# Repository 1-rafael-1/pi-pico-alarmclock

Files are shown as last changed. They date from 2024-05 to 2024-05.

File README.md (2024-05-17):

# pi-pico-alarmclock

Building a working alarmclock based on a Raspberry Pi Pico W

The general idea is to build a device that can reliably wake up my kids who are in an age range, where this is a challenge. So it should sport these features:

+ be somewhat Star wars - themed (not my idea)
+ have a display that shows the time and some other information
+ have a speaker that can play music or sounds, and loudly so
  + have a way to hold music/sound files for that purpose
+ have a thingy that can turn on a bright light, ideally an array of RGB LEDs or some such. Because "when my room is still dark, I cannot properly wake up"
+ have some buttons to set the alarm time and to toggle the alarm
  + without making it too easy to silence the actual alarm when it is going off
+ have the ability to both run on battery power or be powered by a USB charger
+ be built into some enclosure that looks nice, is easy enough to print and assemble and can somehow house the components in a sensible way
+ be fun for daddy to build and program

State of affairs: Wiring and coding is done. There is one issue left to fix (Sound is unreliable, will not turn on as expected 50% of the time).
So this is next: Figure out this bug and then off to designing&printing a case.

## Disclaimer

This project is one of my first projects using MicroPython and electronics. I have some background in software development with niche/proprietary languages and no background at all in electronics and Python. So most of this I figured out as I went.
That being said: This is going to be full of imperfections. Use any of this at Your own risk and in case You spot my mistakes, I am glad to hear of them! Besides that I am happy if this is useful or fun for somebody.

## Description

+ The display shows the current time. A lightsaber-symbol indicates, if the alarm is active or not. A battery indicator shows the battery charge or indicated the device is currently usb-powered.
+ To get the current time, on startup and every 6 hours subsequently the device will connect to Wifi, get the time from a timeserver and update the RTC with that.
+ Button-driven operations:
  + The green button will toggle the alarm active/inactive, when in normal operation mode
  + The yellow button will toggle system info being displayed or the normal time mode being displayed
  + The blue button will enter the mode for setting the alarm time. The current alarm time will be displayed (blinking) and the top area will display a symbol indicating that we are doing some sort of setup.
    + In this mode the green button will increase the hour digits and the yellow button will increase the minutes digits. Pressing blue again will save the new alarm time and resume normal operation.
+ Analog clock: The NeoPixel will show an approximation of an analog clock when in normal operation. The blue light indicates seconds, the green light indicates minutes and the red one indicates hours. When hands meet, their color is mixed. (I know... but I had way too much fun)
+ Alarm:
  + 5 Minutes before the alarm time the NeoPixel will turn off the analog clock and simulate a sunrise, going from few and red lights to more and warm-white lights.
  + At the same time in the indicator area of the display we will show a random color as text, using the button colors. Pressing the appropriate button will proceed to show the next color, until one has pressed all three buttons in the order the device wanted them. Completing the sequence will abort the alarm at any stage. The assumption is: If You are awake enough to have found and pressed the buttons in the random order that You were presented, You should be awake enough to get out of bed.
  + At the actual alarm time the sunrise will becompleted and the NeoPixel will display some fancy lighshow-things. At the same time the Music starts tom play, in my case here I chose the Imperial March, because that is what the kids love.

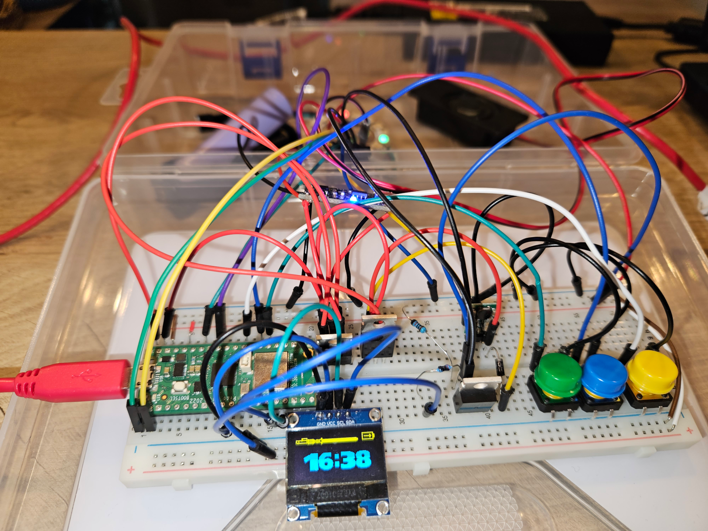
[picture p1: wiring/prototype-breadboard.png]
Prototype on breadboard


## Code

The code project is structured into these main parts: `main.py`, `classes`, and `drivers` as well as `settings` and `media`. 

|part|contents|
|:--|:--|
|main.py|Main script, doing very little besides instantiating.|
|drivers|Drivers and helpers for specific components. I have written none of these myself, each file has a comment saying where I found it.|
|classes|Classes for each logical component used in this project.|
|settings|A few `json` files to remember settings and magic strings.|

One file in settings is not checked into this repository for obvious reasons. Add one `wifi.json` to settings, structured like this:

```json
{
    "ssid": "YOUR SSID",
    "password": "YOUR PASSWORD"
}
```

### Testing and Tests

After a while this projects code got quite messy and I spent a fair amount of time restructuring it into classes with a small brother of dependency injection. This not only helped me to escape dependency hell but also allows for easy mocking and testing in isolation. I did write some tests here and there, typically where I ran into some problem that i was too lazy to iron out by manually testing the full application over and over again. None of this is perfect, but it sure was fun to do.

What I still sorely miss is a way to debug MicroPython Code. Writing anything remotely complex without is no fun.

### media

The folder contains images used for displaying things on the OLED display. The OLED driver provides only very limited support for text, there is no way i found to change font, font size and also (not an issue here) we cannot display all German letters. So if one wants some nicer numbers, some nice state indicators and the like one has to use images. I have used [GIMP](https://www.gimp.org/) to create these images. I have used the `Export as...` function to export them as 'pbm' files. They have to be converted to indexed color and when exporting to pbm they have to be exported as 'raw' format. The OLED driver can then read these files and display them on the screen.

A really good tutorial on how to create these images can be found [here](https://blog.martinfitzpatrick.com/displaying-images-oled-displays/). I would not have figured this out without.

## Components and Wiring

The central part of this project is the Raspberry Pi Pico W. I am sure everything could be done with a different microcontroller, as long as MicroPython is supported. I chose the Pico W because... I had one.

### Components

|Component|Description|
|---|---|
|Microcontroller|Raspberry Pi Pico W|
|OLED Display|SSD1306 compatible I²C OLED Display 128*64 pixels with two color yellow/blue. Input Voltage 3.3V - 5V, but must support 3.3V because that is what we are using. Single-color will work just as well, since the colors are actually fixed to sections of the display and cannot be coded.|
|battery|I use a 18650 Lithium-Polymer battery with 3350mAh. Anything else will work, als long as it fits with the charger module, battery holder and puts out no more than 5V, since You will be plugging it into Pi Pico and the step-up-converter.|
|battery holder|really anything will do, that can hold one Lithium-Polymer unit. Consider adding a switch between battery and charger or be as lazy as me and take out the battery whenever You want to truly power down.|
|charger module|I used a TC4056A module, capable of drawing power from Micro-USB or input pads and capable to charge/discharge the above battery safely.|
|NeoPixel ring|I used WS2812B with 16 RGB LED on it. If You want more LED make sure to check if You can power them safely. Each LED will draw ~60mA and that quickly exceeds either the 300mA the Pico can supply directly or what the step-up-converter attached to the USB or battery power supplies can deliver. In my case here the step-up-converter is rated for 1000mA and so this should be okay.|
|step-up converter|A step up capable to convert 2.5V - 5V to steady 5V. I used BS01 (sometimes found as MT-3608 or HW-085). Required to power the NeoPixel-Ring. There are a ton of these things available everywhere, make sure it is DC-DC and can put out 1000mA for 5V and can convert to that from whatever You expect to come out of Your power supply.|
|speaker|I have used DFplayer Mini 3 Watt 8 Ohm speaker, 70*30*15mm. They can be found in some flavors from multiple vendors. Depending on the form factor You may need to adjust the case, but I guess that cannot be helped since there are so many different of these speakers around.|
|p-channel MOSFET|Two used to switch power modules. I have used IRF9540 which is overkill and and more efficient options exist. These things are rated for up to 100V and the switching voltage is uncomfortably close to USB typical ~5V. So, maybe they now have a higher voltage drop from source to drain, than I would like.|
|n-channel MOSFET|One used to control power supply to mp3 module. I have used IRLZ44N.|
|Schottky diode|One used to prevent power from flowing back into Pi Picos VBUS when powering from battery. Anything rated for up to 5V will do.|
|mp3 module|I have used DFR0299 (DFPlayer), which was easy to wire. It has a micro-sd card slot and an internal amplifier, greatly reducing overall complexity compared to other solutions I found. Also unfortunately my last struggle left... not yet reliable.|
|micro sd card|Really, anything You have lying around, formatted to FAT32.|
|push button|Three used. 13mm diameter, 8mm hight caps on 12x12x7.3mm button - these should be fairly standard. One caps each in yellow, green and blue.|

### Wiring

Here is my best attempt at a wiring diagram. I have used [Circuit Diagram](https://www.circuit-diagram.org/) to create it.

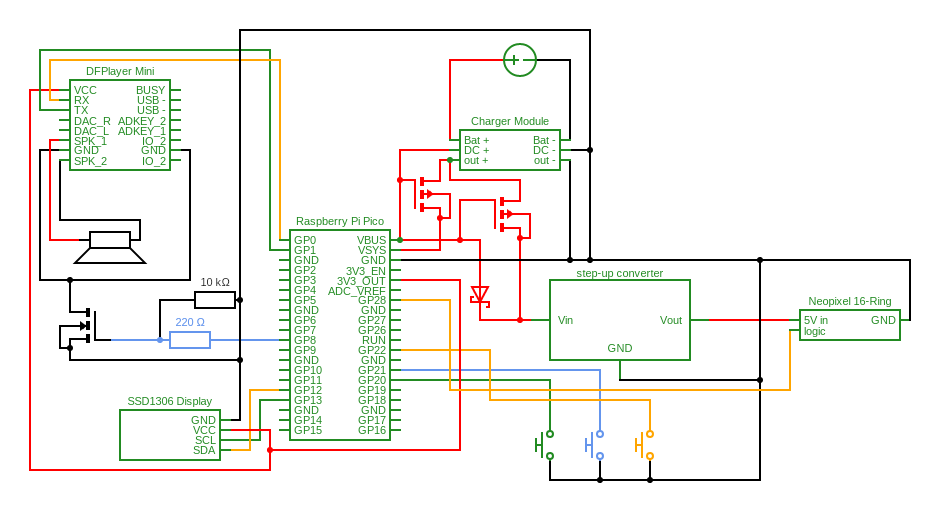
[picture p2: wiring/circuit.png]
Alarm Clock Circuit Power Bypassing Pico


A few things to note here:

+ The buttons are debounced in code, so they have no debouncing circuits.
+ The mp3-module does not normally require a switchable power supply. In my case here I struggled with the DFPlayer I bought, it just would not work anymore after a certain time of idling. The same problem could be replicated by sending it into standby. Not all drivers I found even have the wake-up command implemented and even the ones I tested with never seemed to wake the device up again. At the same time the mp3-module is the most unused one in this entire application, but draws 20mA regardless of whether it does anything or not. So: I decided to power it up and down as needed. To achieve this I used an n-channel-MOSFET. The gate is connected to a GPIO and source to drain sit between the power and the device. That way I can pull the GPIO high to allow the mp3-module to be powered and pull it back low as soon as I do not need it any more. Solves my standby issue and enhances battery life.
+ The power circuit is strongly inspired by the Raspberry Pi Pico documentation. I use one p-channel-MOSFET to cut power from the battery supply, as long as VBUS is powered externally. This is achieved by running a wire from VBUS to the MOSFET gate (VBUS is directly connected to the Micro-USB of the Pico). The second p-channel-MOSFET is used in the same fashion to cut power from the battery to the NeoPixel, as long as VBUS is powered.
+ The NeoPixel needs 5V and so is either supplied from VBUS or from the battery via the step-up-converter. The wire from VBUS to the step-up-converter has a Schottky-diode to prevent power from backfeeding into VBUS when powered from the battery. 
  
### Enclosure and Assembly

See [enclosure](/enclosure/README.md) for information on hoe to print and assemble.

### Power Consumption

These are the assumptions I made regarding power consumption. I did not measure any of these but researched online to arrive at some idea. In general my calculation based on these assumptions matches what I can observe.

|Component|Current (mA)|Current (Ah)|
|:--|:--|:--|
|Pi Pico|40.00|0.04|
|OLED|11.00|0.011|
|NeoPixel|18.00|0.018|
|all Wires, Diodes, MOSFET|8.00|0.0080|
|Step-up-converter loss|4.30|0.0043|

The DRF0299 mp3-module is powered down the entire time, until it needs to play the alarm sound. After that it is powered down again. I am not inclufing it in the above table. In the specs it is rated for 20mA when powered.

The NeoPixel is only active when the alarm is not active and of course during alarm. I put it into the table, as a worst-case scenario where it is never switched off.

The hardest part to put a number on is the Pi Pico itself. Online sources say that under full load it consumes a fraction under .1Ah but then I do not put it under very much load here. On the other hand we also never not use the Pico, there is at least one timer firing every 3.7s to drive the analog clock. I am also still unsure if the main loop iterating over `sleep`n and then `idle` is really the best way to keep the application alive, power-wise. Anyway, I guessed .04Ah for constantly doing stuff but not doing very heavy calculations.

For the OLED I found sources where people measured power consumption of similar devices and from one diagram I found I took the .011Ah. For the NeoPixel I found in the specs that one uses 60mA on full power. The analog clock running most of the time has three LEDs on at 10% brightness, so that should be .018Ah. For all the wires and MOSFET and the diode I basically asked ChatGPT for typical loss and got a fairly believable answer, broken down into a number of assumptions. Best I have, so that would be .0085Ah. The step-up converter actually has an efficiency in the specs and that could be used to calculate the power loss with some accuracy, but in my case here the step-up will either be used to convert from ~5V to 5 or if the battery is powering the battery will be at a voltage somewhere between 2.5V and 4V... so the conversion required will differ all the time. So I assume we will be on 3.5V input on average and to be safe I assume on average 90% efficiency and that ends us at .0043Ah.

So here is what I did to reduce power consumption:

+ **Pico**: The microcontroller is the most power-hungry component by a long shot. The only reason we need it doing things frequently is the seconds hand on the analog clock. I reduced clock speed to 80Mhz in normal operation, when the NeoPixel is not needed. Unfortunately one has to use the full frequency if the NeoPixel is used, because it is driven by state machines and they in turn cycle with the clock -> anything else than 125Mhz throws the timing off balance and the Neopixel will show weird things. I tried to go lower than 80Mhz, but then the OLED Display starts acting strangely.
+ **OLED**: Is not needed at full brightness and should use less power when dimmed. For now I have set contrast to 10 (maximum is 255), that is bright enough.
+ I managed to cut the power to DFPlayer while not used - actually when troubleshooting it not returning from sleep and requiring a fair bit of additional wiring.
+ I managed to cut power to Wifi while not used - also actually when trobleshooting it not being capable of reconnecting properly.

So... before all that I observed ~36h of battery life. I am curious if I now can do better.

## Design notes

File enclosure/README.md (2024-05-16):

# Enclosure for the Pi-Pico Alarm Clock

This document outlines the design, 3D printing, and assembly process of the enclosure for the Pi-Pico Alarm Clock project.

## Design

The enclosure is designed using Autodesk Fusion. The design consists of two main parts: the bottom and the body.

### Outside

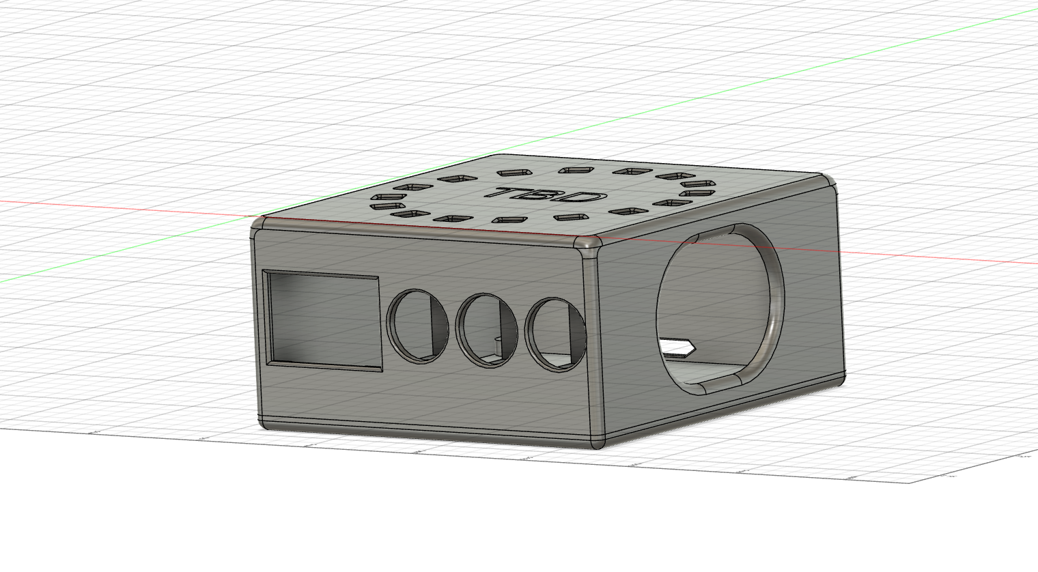
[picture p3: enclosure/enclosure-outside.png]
Enclosure Outside View


### Inside

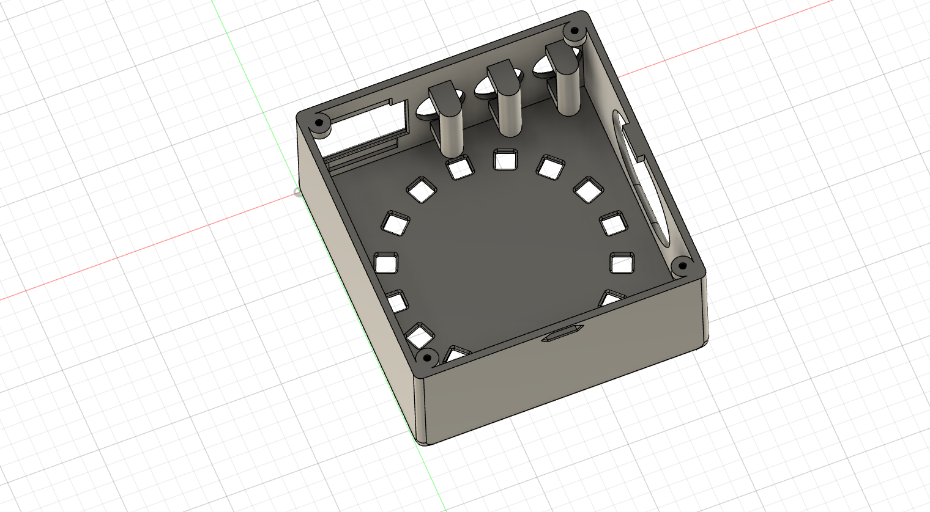
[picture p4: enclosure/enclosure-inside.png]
Enclosure Inside View


### Bottom

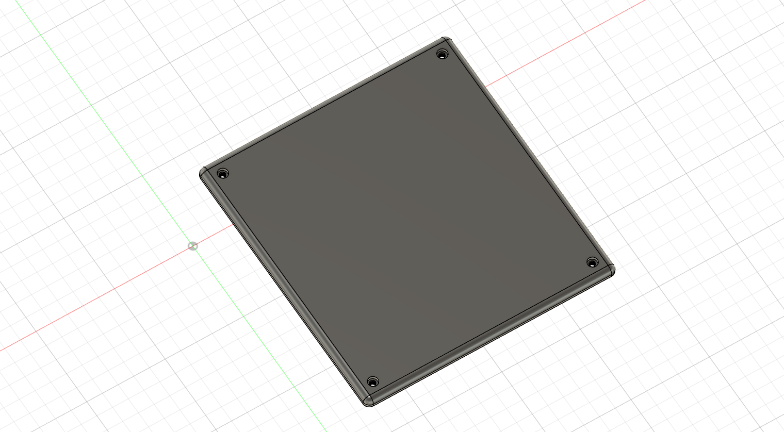
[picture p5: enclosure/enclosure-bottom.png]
Enclosure Bottom View


The bottom part mounts the Raspberry Pi Pico and a few of the smaller components. The battery, the speaker, the buttons, the NeoPixel as well as the display are assembled into the main body.

## Modifying the Design

Most of the components used for this product are manufactured by a great variety of companies, many components being clones of other components. That makes them cheap and readily available but also makes them come in many different sizes.

It is highly likely, that the enclosure will not fit with the components and in that case adjustments have to be made. For this purpose find the Autodesk Fusion Archive File here:

[Fusion Archive File](enclosure.f3d)

This was my very first use of a CAD software, so be warned... that being said, this is how things are organized:

+ For the NeoPixel Ring, find the sketch for the `top` and locate the rectangle that is constrained by construction lines. Change dimensions to alter NeoPixel size or throw all the rectangles out and add Your own (in that case, extrude them).
+ For the Name, find the sketch `Name` and modify the text. As soon as You add letters, these new letters will not be extruded. Extrude from the bottom of the new letters 0.3mm up and that should do the trick.
+ For the buttons I am reasonably sure fitting buttons can be found. If the button design needs changing, a number of things need to be done:
  + sketch `front buttons` is for the holes in the front
  + sketch `front button mount base` is for the mounting of the buttons, part 1
  + sketch `front button mount bridge` is for the mounting of the buttons, part 2
+ For the display (a likely thing that won't fit) You need a hole for the display itself and then because the display has a flat cable on the underside on the front and maybe even also som soldered pins sticking out the front, some depressions in the wall are needed:
  + the display itsef is found in sketch `front`
  + sketch `display cable cover` handles the flat cable
  + sketch `front display pin allowance` handles the pins jutting out on the front side
+ For the speaker edit the sketch `right`
+ For the MicroUSB hole edit sketch `back`. You may want to change that to USB-C depending on the microcontroller used.
+ the sketch `left` is basically just a plain rectangle
+ the sketch `bottom` is almost plain, besides the four holes to attach the bottom to the enclosure. Should work with M2 screws 5-7mm long
  
## 3D Printing

The enclosure is designed to be 3D printed. Since anybody will need to adjust sizes, change the name on the top li, etc. I am not including STL files here. Use Autodesk Fusion and the above Fusion Archive File and then export the parts to STL after modifying accordingly. Export the top lid together with the name body, the body and the bottom separately.

In my case I found that between the slicer and the print I need to add 0.63% to the objects sizes. Calibrate that by printing a plain square and using calipers to find how much the result diverges from the design. This will be very different depending on the filament, the print temperature and probably also on the printer itself.

I used these general settings in my slicer:

+ 2 wall layers and adaptive cubic infill of 15%
+ organic tree support, allow to add supports on the model itself. Supports with 2 wall layers and filled with a honeycomb pattern. They will lean out quite a bit and need to be stronger than usual.
+ no fan for the first 5 layers
+ no raft, no brim - not required in my case when the fan is off for the first few layers
  
## Assembly

TBD

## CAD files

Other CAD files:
enclosure/enclosure.f3d

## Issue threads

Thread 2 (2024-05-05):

alarm sound is unreliable

1-rafael-1, 2024-05-05:
On a freshly started system, the alarm sound can be played from the class SoundManager. I have  also had successful runs with the alarm sound playing in an actual alarm sequence.

Most of the time, though, the DFPlayer appears unresponsive to the commands sent to it. This is hard to test and pinpoint, but ist seems to me the device is not initialized and handled the way it should be.

Things to check:
+ no reliable repro yet: isolate the cirsumstance, in which the module stops responding as expected
+ unconfirmed assumpotion: when testing I usually reset the code execution, but do not cut power. Maybe the device remains active and then does not like being re-initialized. That would fit general documentation on UART devices in the MicroPython Docs -> find a way to deinitialize properly; Test if cutting power will reliably make the device respond again.
+ unconfirmed assumption 2: taking the SD Card out of the device and re-inserting it seems to re-establish functionality. Maybe this is some sort of reset, maybe connected to the above.
+ unconfirmed assumption 3: there is a command to send the device to standby, but the device specs do not clearly say what must be done to wake the device up again... there is a normalWorking, ... but what does that do?
+ the driver does not seem to implement all the device communication, but nothing obviously related to my problem comes to mind. There seem to be some state messages that can be read from the device and this may help. Requires extending the driver to read from the device, ATM the driver only sends commands.

Closed 2024-05-16.

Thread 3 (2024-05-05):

more precise modules list

1-rafael-1, 2024-05-05:
add info for HW-0815 -> can be found as "BS01 or MT-3608"
push buttons are D6R30F1LFS

1-rafael-1, 2024-05-14:
changed buttons again, to have better mounting options

Closed 2024-05-14.

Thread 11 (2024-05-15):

there is no way to power the device up or down

1-rafael-1, 2024-05-15:
This is a stupid one - how did I forget this?
While developing the need never arose, but there actually is no way to actively switch the entire device off (and back on).

Ideally a way shpuld be found, to make this work without adding more hardware.
So, maybe this will work:

+ add a power down sequence to the system info, need to expand that to enable this (see below)
+ when powered down, actually enter deepsleep, woken by any button pin going high
+ the device should in theory just start the program as if just being turned on
+ when we run the battery dry in deepsleep, powering the device via USB will also initiate the normal start

sytem info menu:
Right now this is just one page with a few system info thingies. We could do it like this:

+ yellow button no longer starts the sytem info, but shows some text menu: (green: sys. info, blue: power down)
+ yellow again: like today, go back to normal mode
+ green: open the system info
+ blue: initiate power down, maybe add a screen saying goodbye.

Closed 2024-05-17.

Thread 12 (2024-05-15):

enclosure design: bottom fastening too weak. Top should be printed separately.

1-rafael-1, 2024-05-15:
The bottom can be attached once and fits well, but the bolts break very easily when removing the bottom -> redesign to use proper screws, so that tge enclosure can be opened for maintenance.

The top works well as such, but it needs to be printed upside-down and so the outer layer must be printed on the build plate. While that works, it does not look as nice as expected. -> redesign to separate the top from the enclosure body. Doesd not need to be opened again for maintenance, so can be glued on in assembly.

Closed 2024-05-16.

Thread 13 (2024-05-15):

updating the rtc is unreliable

1-rafael-1, 2024-05-15:
every 6 hours the RTC is updated ATM. To do this a wifi connection is established, a service called and then the rtc gets updated and the wifo connection gets closed.

This does not seem to work, sometimes the onboard led (indicating connection) is lit up but never shut off again.

Either: The wifi connection cannot be closed
Or: The service is unavailable
Or: The response times out

Normal operation resumes oncompromised.

1-rafael-1, 2024-05-18:
resolved together with #27

Closed 2024-05-18.

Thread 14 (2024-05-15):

battery charge state is imprecise

1-rafael-1, 2024-05-15:
The battery charge lower bound should be 2.5V by the charger module specs, but the device powers down before that, so maybe either the calculation or the charger or whatever behave unexpectedly.

Closed 2024-05-25.

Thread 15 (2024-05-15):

introduce rolling log for system data

1-rafael-1, 2024-05-15:
see #13  and #14 and likely more things: There is no log to establish what happened, when something happened.

There should be a simple log file to record what happens on the device.

Introduce log_mgr class, instantiate this when some setup config says that we should.

make a log.txt file of some sort, it should be rolling so it will not grow too much.

This should be logged:

+ activate alarm
+ deactivate alarm
+ set alarm time
+ raise alarm
+ quit alarm by timeout
+ quit alarm by manual intervention
+ connect wifi
+ disconnect wifi
+ call time server
+ handle time server response
+ update rtc
+ start sunrise
+ start of each neopixel thingy
+ start sound
+ end sound
+ every 10min: battery data, memory data
+ enter menu
+ exit menu
+ enter system info
+ exit system info
+ .... whatever else comes to mind

Closed 2024-05-20.

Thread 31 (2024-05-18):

rework README entirely, after assembly

1-rafael-1, 2024-05-18:

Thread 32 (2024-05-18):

switching to an from usb power supply should directly change the battery symbol

1-rafael-1, 2024-05-18:
right now the display timer needs to cycle in order to update the battery symbol.
Not all that important,

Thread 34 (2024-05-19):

introduce optio  to set clock manually if wifi not accessible

1-rafael-1, 2024-05-19:
Right now there is no way to use the device, if it boots to not finding wifi

Optimum solution:

Booting, attempt to connect wifi, on failure: Interrupt booting, display the time blinking, let the user set hours and minurtes and confirm with blue button, continue booting.

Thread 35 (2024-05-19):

powerdown has issues powering back up

1-rafael-1, 2024-05-19:
...and once that is managed, we end up with the wrong state region in the display.

Closed 2024-05-19.

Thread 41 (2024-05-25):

evaluate circuit optins for the step-up converter: do we need the second MOSFET or should we use a diode?

1-rafael-1, 2024-05-25:
ATM the step up is switched by the second p-channel mosfet.
This works, but maybe a quick measuring is a good idea, do we loose more power through the MOSFET opposed to another Schottky diode?

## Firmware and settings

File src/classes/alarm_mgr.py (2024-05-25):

import micropython
import json
from utime import sleep, time, localtime
from machine import Timer
from urandom import randint
import _thread

class AlarmManager:
    def __init__(self, state_mgr):
        self.state_mgr = state_mgr
        self.alarm_timer = None
        self.alarm_active = False
        self.alarm_raised = False
        self.alarm_time = '{:02d}:{:02d}'.format(0,0) # ToDo: move to AlarmManager
        self.alarm_raised = False # ToDo: move to AlarmManager 
        self.alarm_raised_time = None
        self.last_alarm_stopped_time = None
        self.alarm_quit_button_sequence = []
        self.alarm_sequence_thread = None
        self.alarm_sequence_running = False
        self.alarm_sequence_sound_running = False
    
    def initialize(self):
        self.read_alarm_time()
        self.read_alarm_active()    

    def set_alarm_active(self, value):
        self.state_mgr.log_emit(f'Alarm active: {self.alarm_active}', self.__class__.__name__)
        self.alarm_active = value
        self.write_alarm_active()

    def is_alarm_active(self):
        return self.alarm_active
    
    def set_alarm_raised(self, value):
        self.alarm_raised = value

    def is_alarm_raised(self):
        return self.alarm_raised
    
    def set_alarm_time(self, time):
        self.alarm_time = time

    def get_alarm_time(self):
        return self.alarm_time
    
    def read_alarm_time(self):
        with open('settings//alarm.json', 'r') as file:
            data = json.load(file)
            self.set_alarm_time(data['alarm_time'])

    def write_alarm_time(self):
        with open('settings//alarm.json', 'r') as file:
            data = json.load(file)
        data['alarm_time'] = self.get_alarm_time()
        with open('settings//alarm.json', 'w') as file:
            json.dump(data, file)
        self.state_mgr.log_emit(f'Alarm time: {self.get_alarm_time()}', self.__class__.__name__)    

    def read_alarm_active(self):
        with open('settings//alarm.json', 'r') as file:
            data = json.load(file)
            self.set_alarm_active(data['alarm_active'])

    def write_alarm_active(self):
        with open('settings//alarm.json', 'r') as file:
            data = json.load(file)
        data['alarm_active'] = self.is_alarm_active()
        with open('settings//alarm.json', 'w') as file:
            json.dump(data, file)

    def start_alarm_timer(self):
        if self.alarm_timer is None:
            self.state_mgr.log_emit("Alarm timer started", self.__class__.__name__)
            self.alarm_timer = Timer(period=30000, mode=Timer.PERIODIC,callback=lambda t: self.check_alarm())
        
    def stop_alarm_timer(self):
        if self.alarm_timer is not None:
            self.state_mgr.log_emit("Alarm timer stopped", self.__class__.__name__)
            self.alarm_timer.deinit()
            self.alarm_timer = None
        self.set_alarm_raised(False)

    def set_last_alarm_stopped_time(self, time):
        self.last_alarm_stopped_time = time

    def clear_last_alarm_stopped_time(self):
        self.last_alarm_stopped_time = None

    def is_last_alarm_just_stopped(self):
        if self.last_alarm_stopped_time is not None:
            if time() - self.last_alarm_stopped_time <= 600:
                return True
        return False

    @micropython.native
    def check_alarm(self):
        if self.is_alarm_active() and not self.is_alarm_raised() and not self.is_last_alarm_just_stopped():
            current_time = localtime()
            current_hours = current_time[3]
            current_minutes = current_time[4]
            alarm_hours, alarm_minutes = map(int, self.get_alarm_time().split(':'))
            self.state_mgr.log_emit(f'Alarm time: {self.get_alarm_time()} Current time: {current_hours}:{current_minutes}', self.__class__.__name__)
        
            time_diff = (current_hours * 60 + current_minutes) - (alarm_hours * 60 + alarm_minutes)
            
            if time_diff < -30:
                time_diff += 24 * 60
        
            if -5 <= time_diff <= 3:
                if not self.is_alarm_raised():
                    self.raise_alarm()
        elif self.is_alarm_raised():
            if self.alarm_raised_time is not None:
                self.state_mgr.log_emit(f"elapsed seconds since alarm raised: {time() - self.alarm_raised_time}", self.__class__.__name__)
            if self.alarm_raised_time is not None:
                if time() - self.alarm_raised_time >= 300:
                    if not self.alarm_sequence_sound_running:
                        self.alarm_sequence_sound_running = True
                        self.state_mgr.sound_alarm_sequence()
                if time() - self.alarm_raised_time >= 600:
                    self.quit_alarm()
                    self.alarm_raised_time = None

    @micropython.native
    def randomize_quit_button_sequenze(self):
        colors = ['green', 'blue', 'yellow']
        self.alarm_quit_button_sequence = []
        while colors:
            index = randint(0, len(colors) - 1)
            self.alarm_quit_button_sequence.append(colors.pop(index))

    def display_first_quit_button_sequence(self):
        self.state_mgr.display_alarm_quit_sequence(0)

    def remove_first_quit_button_sequence(self):
        self.alarm_quit_button_sequence.pop(0)

    @micropython.native
    def alarm_sequence(self):
        self.set_alarm_sequence_running(True)
        self.state_mgr.neopixel_all_off()
        self.state_mgr.neopixel_sunrise(duration=300)
        self.state_mgr.sound_alarm_sequence() # async, non-blocking
        while self.is_alarm_raised():
            for i in range(7):
                if not self.is_alarm_raised():
                    break
                if i == 0: 
                    self.state_mgr.neopixel_all_off()
                elif i == 1: 
                    self.state_mgr.neopixel_turning_wheel(self.state_mgr.neopixel_get_color(255, 255, 255), delay=0.3, loops=10)
                elif i == 2: 
                    self.state_mgr.neopixel_all_off()
                elif i == 3: 
                    self.state_mgr.neopixel_chase([self.state_mgr.neopixel_get_color(255, 0, 0), self.state_mgr.neopixel_get_color(0, 255, 0), self.state_mgr.neopixel_get_color(0, 0, 255), self.state_mgr.neopixel_get_color(255, 255, 0), self.state_mgr.neopixel_get_color(0, 255, 255)], delay=0.1, loops=5)
                elif i == 4: 
                    self.state_mgr.neopixel_all_off()
                elif i == 5: 
                    self.state_mgr.neopixel_pendulum([self.state_mgr.neopixel_get_color(255, 0, 0), self.state_mgr.neopixel_get_color(0, 255, 0), self.state_mgr.neopixel_get_color(0, 0, 255)], delay=0.1, loops=5)
                elif i == 6: 
                    self.state_mgr.neopixel_all_off() 
        self.state_mgr.neopixel_all_off()
        self.set_alarm_sequence_running(False)
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

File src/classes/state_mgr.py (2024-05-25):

import _thread
from utime import sleep
from machine import freq
from classes.log_mgr import LogManager
from classes.wifi_mgr import WifiManager
from classes.neopixel_mgr import NeoPixelManager
from classes.display_mgr import DisplayManager
from classes.time_mgr import TimeManager
from classes.sound_mgr import SoundManager
from classes.btn_mgr import ButtonManager
from classes.menu_mgr import MenuManager
from classes.power_mgr import PowerManager
from classes.alarm_mgr import AlarmManager
from classes.lowpower_mgr import LowPowerManager

class StateManager:
    def __init__(self):
        self.log_manager = LogManager(self)
        self.power_manager = PowerManager(self)
        self.wifi_manager = WifiManager(self)
        self.time_manager = TimeManager(self)
        self.neopixel_manager = NeoPixelManager(self)
        self.display_manager = DisplayManager(self)
        self.menu_manager = MenuManager(self)
        self.button_manager = ButtonManager(self, green_pin=20, blue_pin=21, yellow_pin=22)
        self.sound_manager = SoundManager(self)
        self.alarm_manager = AlarmManager(self)
        self.lowpower_manager = LowPowerManager(self, green_pin=self.button_manager.get_green_pin(), blue_pin=self.button_manager.get_blue_pin() , yellow_pin=self.button_manager.get_yellow_pin())
        self.lock = _thread.allocate_lock()

    def initialize(self):
        self.log_initialize()
        self.log_emit("Initializing StateManager", self.__class__.__name__)

        self.set_full_clock_speed()

        self.display_initialize()
        self.display_compose_boot('display mgr')

        self.menu_initialize()

        self.display_compose_boot('power mgr')
        self.power_initialize()

        self.display_compose_boot('wifi + rtc')
        self.time_initialize()
        self.time_start_update_rtc_timer()

        self.display_compose_boot('alarm mgr')
        self.alarm_initialize()
        self.alarm_start_alarm_timer()

        self.display_compose_boot('neopixel')
        self.neopixel_initialize()
        if not self.alarm_is_alarm_active():
            self.neopixel_start_update_analog_clock_timer()

        self.display_compose_boot('button mgr') 
        self.button_initialize()
        
        self.display_compose_boot('normal op')
        self.display_initialize_normal_operation()
        self.display_start_update_display_timer()

        self.log_emit("StateManager initialized", self.__class__.__name__)

    # region global state methods
    def set_full_clock_speed(self):
        freq(125000000) # 125 MHz, default clock speed for RP2040
        sleep(1) # wait for clock speed to stabilize
        self.log_emit(f"Clock speed set to: {freq()}", self.__class__.__name__)

    def set_low_clock_speed(self):
        freq(20000000) # 20 MHz, lowest clock speed for RP2040
        sleep(1) # wait for clock speed to stabilize
        self.log_emit(f"Clock speed set to: {freq()}", self.__class__.__name__)
    # endregion

    # region PowerManager methods
    def power_initialize(self):
        self.power_manager.initialize()

    def power_get_battery_state(self):
        return self.power_manager.get_battery_state()
    
    def power_get_battery_charge_percentage(self):
        return self.power_manager.get_battery_charge_percentage()
    
    def power_is_usb_powered(self):
        return self.power_manager.is_usb_powered()
    
    def power_read_vsys(self):
        self.power_manager.read_vsys()

    def power_get_vsys_voltage(self):
        return self.power_manager.vsys_voltage
    
    def power_read_temperature(self):
        self.power_manager.read_temperature()

    def power_get_temperature(self):
        return self.power_manager.get_temperature()
    
    def power_log_vsys(self):
        self.power_manager.log_vsys()
    # endregion

    # region WifiManager methods
    def wifi_connect_wifi(self, max_wait=20, indicator=True):
        self.wifi_manager.connect(max_wait=20, indicator=True)

    def wifi_disconnect_wifi(self, max_wait=20, indicator=True):
        self.wifi_manager.disconnect(max_wait=20, indicator=True)

    def wifi_reconnect_wifi(self, max_wait=20):
        self.wifi_manager.reconnect(max_wait=20)

    def wifi_is_network_up(self):
        return self.wifi_manager.is_network_up()
    # endregion

    # region MenuManager methods
    def menu_initialize(self):
        self.menu_manager.initialize()

    def menu_press_green_button(self):
        self.menu_manager.press_green_button()

    def menu_press_blue_button(self):
        self.menu_manager.press_blue_button()

    def menu_press_yellow_button(self):
        self.menu_manager.press_yellow_button()

    def menu_set_state(self, state):
        self.menu_manager.set_state(state)

    def menu_get_state(self):
        return self.menu_manager.get_state()
    
    def menu_set_system_state(self, state):
        self.menu_manager.set_system_state(state)
    
    def menu_get_system_state(self):
        return self.menu_manager.get_system_state()
    
    def menu_is_menu_active(self):
        return self.menu_manager.get_state() in ['system','menu']
    # endregion

    # region DisplayManager methods
    def display_initialize(self):
        self.display_manager.initialize()

    def display_clear(self):
        self.display_manager.clear()

    def display_compose(self):
        self.display_manager.compose()

    def display_compose_boot(self, message):
        self.display_manager.compose_boot(message)

    def display_state_region(self):
        self.display_manager.display_state_region()

    def display_display_battery_state(self):
        self.display_manager.display_battery_state()

    def display_start_update_display_timer(self):
        self.display_manager.start_update_display_timer()

    def display_stop_update_display_timer(self):
        self.display_manager.stop_update_display_timer()

    def display_time(self, time):
        self.display_manager.display_time(time)

    def display_start_blinking_set_alarm_time(self):
        self.display_manager.start_blinking_set_alarm_time()

    def display_stop_blinking_set_alarm_time(self):
        self.display_manager.stop_blinking_set_alarm_time()

    def display_clear_first_row(self):
        self.display_manager.clear_first_row()

    def display_alarm_quit_sequence(self, index):
        self.display_manager.display_alarm_quit_sequence(index)

    def display_initialize_normal_operation(self):
        self.display_manager.initialize_normal_operation()
    # endregion

    # region NeoPixelManager methods
    def neopixel_initialize(self):
        self.neopixel_manager.initialize()

    def neopixel_all_off(self):
        self.neopixel_manager.all_off()

    def neopixel_get_color(self, red, green, blue):
        return self.neopixel_manager.get_color(red, green, blue)
    
    def neopixel_pendulum(self, colors, delay, loops):
        self.neopixel_manager.pendulum(colors, delay, loops)
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

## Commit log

2024-05-14 update step-up converter makes and push-button details (#6)
2024-05-14 7 add enclosure printing information (#8)
    * Add enclosure design files and printing instructions
    * upd README
    ---------
    [enclosure-body.stl, enclosure-bottom.stl, enclosure.f3d]
2024-05-16 2 alarm sound is unreliable (#17)
    * add new driver; does not help; begin preparing for hard power-down
    * Add n-channel MOSFET for controlling power supply to mp3 module; expand readme
    * Update power pin for DFPlayerMini in SoundManager class
    * upd workspace
    * Update n-channel MOSFET type for controlling power supply to mp3 module
    * wiring finalized
    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
2024-05-16 update enclosure design
    [enclosure-body.stl, enclosure-bottom.stl, enclosure.f3d]
2024-05-16 RC3 of the design
    [enclosure.f3d]
2024-05-17 fix some tests (#26)
    [app_manager.py, display_mgr.py, menu_mgr.py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]
2024-05-17 11-there-is-no-way-to-power-the-device-up-or-down (#27)
2024-05-18 reduced clock speed interferes with normal operation
    [neopixel_mgr.py, state_mgr.py]
2024-05-19 35-powerdown-has-issues-powering-back-up (#37)
2024-05-20 15-introduce-rolling-log-for-system-data (#39)
    * cannot throw in main without the board freezing
    * cannot auto-update after code upload: board freezes
    * introduce LogManager
    * log a bunch of things
    * Fix timestamp format in log entry creation
    * Update logging settings in ApplicationManager
    [alarm_mgr.py, app_manager.py, btn_mgr.py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]
2024-05-25 Update lower_bound value in PowerManager constructor (#40)
2024-05-25 36-tidy-up-state-manager-class-a-number-of-states-in-the-constructur-should-move-to-the-respective-classes (#42)
    * get button pins through button_mgr
    * remove comments from alarm_mgr; move neopixel sleep after all_off to neopixel_mgr
    * refactor state_mgr, move all states to respective classes
